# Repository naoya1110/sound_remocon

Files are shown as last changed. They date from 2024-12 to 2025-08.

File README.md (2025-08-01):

# sound_remocon

このリポジトリは、サウンドリモコンの開発データ（KiCadファイル等）をまとめたものです。

## ディレクトリ構成

- **v2/**  
  バージョン2
  - **kicad/**  
    v2用のKiCadプロジェクトファイル
    - `sound_remocon_v2/`：v2用KiCadプロジェクト・Gerberファイル
    - `plot_v2_20250704/`：v2 PCB製造用Gerberファイル
  - **ltspice/**  
    LTspiceシミュレーションファイル
    - `mixer_circuit_simulation.asc`：ミキサー回路シミュレーション
  - **pico_codes/**  
    - `pico_codes\sound_remocon_v2\sound_remocon_v2.ino` ラズパイPico用ファームウェア・コード

- **v1/**  
  バージョン1
  - **kicad/**  
    KiCadプロジェクトファイル、ネットリスト、シンボルライブラリ、フットプリント、Gerberファイルなど。

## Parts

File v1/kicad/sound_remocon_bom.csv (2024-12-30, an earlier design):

Reference | Value | Datasheet | Footprint | Qty | DNP
C1,C2,C3,C4,C5,C6 | 0.1u | ~ | Capacitor_THT:C_Disc_D3.8mm_W2.6mm_P2.50mm | 6
Clpf1 | 1n | ~ | Capacitor_THT:C_Disc_D3.8mm_W2.6mm_P2.50mm | 1
Cls1,Clx1,Cly1,Crs1,Crx1,Cry1 | C | ~ | Capacitor_THT:C_Disc_D3.8mm_W2.6mm_P2.50mm | 6
Cout1 | 4.7u | ~ | Capacitor_THT:C_Disc_D4.7mm_W2.5mm_P5.00mm | 1
J1,J2 | Conn_01x02_Pin | ~ | TerminalBlock:TerminalBlock_bornier-2_P5.08mm | 2
JoyStick_left1,JoyStick_right1 | RKJXV122400R |  | myjoystick:RKJXV122400R | 2
LED1 | LED | ~ | LED_THT:LED_D3.0mm | 1
R1,R2,R3,R4,R5,R6,Rls1,Rls2,Rls3,Rlx1,Rlx2,Rlx3,Rly1,Rly2,Rly3,Rmx1,Rmx2,Rmx3,Rna1,Rna2,Rrs1,Rrs2,Rrs3,Rrx1,Rrx2,Rrx3,Rry1,Rry2,Rry3 | 10k | ~ | Resistor_THT:R_Axial_DIN0207_L6.3mm_D2.5mm_P7.62mm_Horizontal | 29
Rled1 | R | ~ | Resistor_THT:R_Axial_DIN0207_L6.3mm_D2.5mm_P7.62mm_Horizontal | 1
Rlpf1 | 3.3k | ~ | Resistor_THT:R_Axial_DIN0207_L6.3mm_D2.5mm_P7.62mm_Horizontal | 1
Rls4,Rlx4,Rly4,Rrs4,Rrx4,Rry4 | ~ | ~ | Resistor_THT:R_Axial_DIN0207_L6.3mm_D2.5mm_P7.62mm_Horizontal | 6
Rout1,Rout2 | 50k | ~ | Resistor_THT:R_Axial_DIN0207_L6.3mm_D2.5mm_P7.62mm_Horizontal | 2
U1,U2,U3,U4 | NJM4580 | http://www.njr.com/semicon/PDF/NJM4580_E.pdf | Package_DIP:DIP-8_W7.62mm | 4

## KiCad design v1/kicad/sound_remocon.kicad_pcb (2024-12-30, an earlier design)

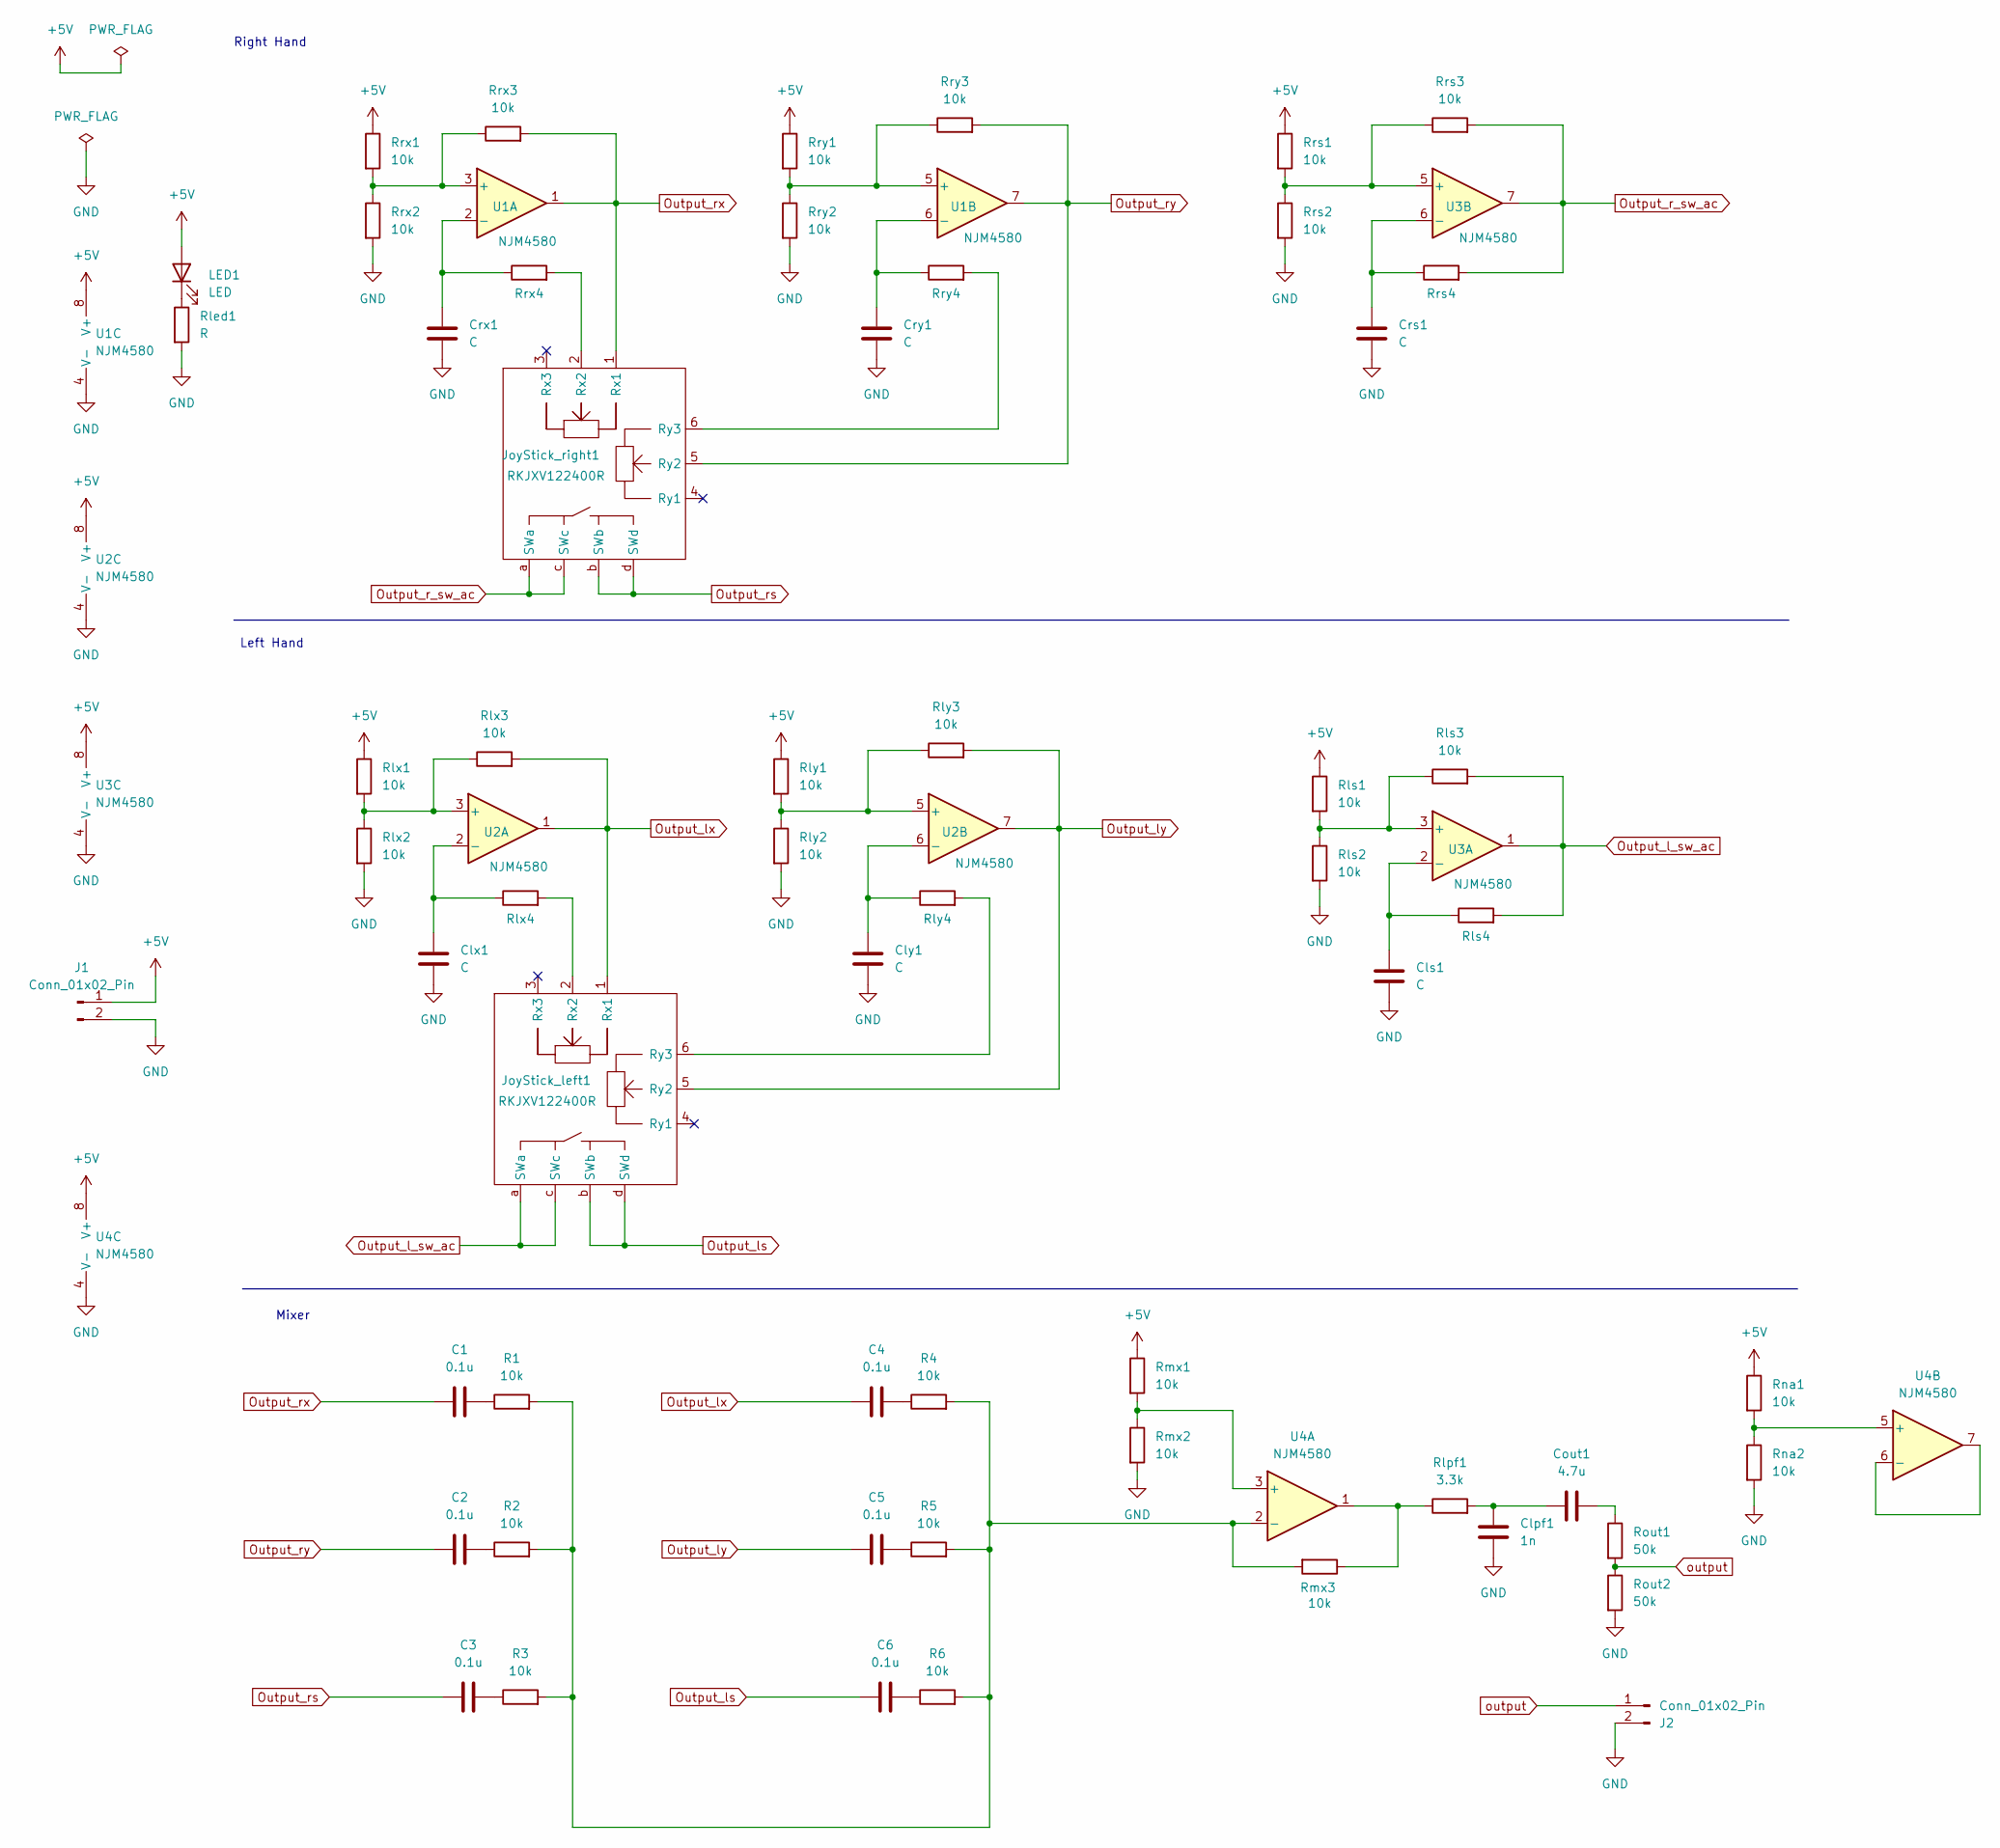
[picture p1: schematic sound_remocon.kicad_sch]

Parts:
C1, C2, C3, C4, C5, C6: 0.1u; C_Disc_D3.8mm_W2.6mm_P2.50mm
Clpf1: 1n; C_Disc_D3.8mm_W2.6mm_P2.50mm
Cls1: C; C_Disc_D3.8mm_W2.6mm_P2.50mm
Clx1: C; C_Disc_D3.8mm_W2.6mm_P2.50mm
Cly1: C; C_Disc_D3.8mm_W2.6mm_P2.50mm
Cout1: 4.7u; C_Disc_D4.7mm_W2.5mm_P5.00mm
Crs1: C; C_Disc_D3.8mm_W2.6mm_P2.50mm
Crx1: C; C_Disc_D3.8mm_W2.6mm_P2.50mm
Cry1: C; C_Disc_D3.8mm_W2.6mm_P2.50mm
J1, J2: Conn_01x02_Pin; TerminalBlock_bornier-2_P5.08mm
JoyStick_left1: RKJXV122400R
JoyStick_right1: RKJXV122400R
LED1: LED; LED_D3.0mm
R1, R2, R3, R4, R5, R6: 10k; R_Axial_DIN0207_L6.3mm_D2.5mm_P7.62mm_Horizontal
Rled1: R; R_Axial_DIN0207_L6.3mm_D2.5mm_P7.62mm_Horizontal
Rlpf1: 3.3k; R_Axial_DIN0207_L6.3mm_D2.5mm_P7.62mm_Horizontal
Rls1, Rls2, Rls3: 10k; R_Axial_DIN0207_L6.3mm_D2.5mm_P7.62mm_Horizontal
Rls4: R_Axial_DIN0207_L6.3mm_D2.5mm_P7.62mm_Horizontal
Rlx1, Rlx2, Rlx3: 10k; R_Axial_DIN0207_L6.3mm_D2.5mm_P7.62mm_Horizontal
Rlx4: R_Axial_DIN0207_L6.3mm_D2.5mm_P7.62mm_Horizontal
Rly1, Rly2, Rly3: 10k; R_Axial_DIN0207_L6.3mm_D2.5mm_P7.62mm_Horizontal
Rly4: R_Axial_DIN0207_L6.3mm_D2.5mm_P7.62mm_Horizontal
Rmx1, Rmx2, Rmx3: 10k; R_Axial_DIN0207_L6.3mm_D2.5mm_P7.62mm_Horizontal
Rna1, Rna2: 10k; R_Axial_DIN0207_L6.3mm_D2.5mm_P7.62mm_Horizontal
Rout1, Rout2: 50k; R_Axial_DIN0207_L6.3mm_D2.5mm_P7.62mm_Horizontal
Rrs1, Rrs2, Rrs3: 10k; R_Axial_DIN0207_L6.3mm_D2.5mm_P7.62mm_Horizontal
Rrs4: R_Axial_DIN0207_L6.3mm_D2.5mm_P7.62mm_Horizontal
Rrx1, Rrx2, Rrx3: 10k; R_Axial_DIN0207_L6.3mm_D2.5mm_P7.62mm_Horizontal
Rrx4: R_Axial_DIN0207_L6.3mm_D2.5mm_P7.62mm_Horizontal
Rry1, Rry2, Rry3: 10k; R_Axial_DIN0207_L6.3mm_D2.5mm_P7.62mm_Horizontal
Rry4: R_Axial_DIN0207_L6.3mm_D2.5mm_P7.62mm_Horizontal
U1, U2, U3, U4: NJM4580; DIP-8_W7.62mm

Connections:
+5V: J1.1, LED1.2 (A), Rls1.1, Rlx1.1, Rly1.1, Rmx1.1, Rna1.1, Rrs1.1, Rrx1.1, Rry1.1, U1.8 (V+), U2.8 (V+), U3.8 (V+), U4.8 (V+)
GND: Clpf1.2, Cls1.2, Clx1.2, Cly1.2, Crs1.2, Crx1.2, Cry1.2, J1.2, J2.2, Rled1.2, Rls2.2, Rlx2.2, Rly2.2, Rmx2.2, Rna2.2, Rout2.2, Rrs2.2, Rrx2.2, Rry2.2, U1.4 (V-), U2.4 (V-), U3.4 (V-), U4.4 (V-)
unnamed: C1.2, R1.1
unnamed: C2.2, R2.1
unnamed: C3.2, R3.1
unnamed: C4.2, R4.1
unnamed: C5.2, R5.1
unnamed: C6.2, R6.1
unnamed: Clpf1.1, Cout1.1, Rlpf1.2
unnamed: Cout1.2, Rout1.1
unnamed 10: JoyStick_left1.2 (Rx2), Rlx4.2; also elsewhere on the board
unnamed 11: JoyStick_left1.6 (Ry3), Rly4.2; also elsewhere on the board
unnamed 12: JoyStick_right1.2 (Rx2), Rrx4.2; also elsewhere on the board
unnamed 13: JoyStick_right1.6 (Ry3), Rry4.2; also elsewhere on the board
unnamed: LED1.1 (K), Rled1.1
unnamed: Rlpf1.1, Rmx3.1, U4.1
unnamed: Rrx1.2, Rrx2.1, Rrx3.1, U1.3 (+)
unnamed: Crx1.1, Rrx4.1, U1.2 (-)
unnamed: Rry1.2, Rry2.1, Rry3.1, U1.5 (+)
unnamed: Cry1.1, Rry4.1, U1.6 (-)
unnamed: Rlx1.2, Rlx2.1, Rlx3.1, U2.3 (+)
unnamed: Clx1.1, Rlx4.1, U2.2 (-)
unnamed: Rly1.2, Rly2.1, Rly3.1, U2.5 (+)
unnamed: Cly1.1, Rly4.1, U2.6 (-)
unnamed: Rls1.2, Rls2.1, Rls3.1, U3.3 (+)
unnamed: Cls1.1, Rls4.1, U3.2 (-)
unnamed: Rrs1.2, Rrs2.1, Rrs3.1, U3.5 (+)
unnamed: Crs1.1, Rrs4.1, U3.6 (-)
unnamed: Rmx1.2, Rmx2.1, U4.3 (+)
unnamed: R1.2, R2.2, R3.2, R4.2, R5.2, R6.2, Rmx3.2, U4.2 (-)
unnamed: Rna1.2, Rna2.1, U4.5 (+)
unnamed: U4.6 (-), U4.7
Output_l_sw_ac: JoyStick_left1.a (SWa), JoyStick_left1.c (SWc), Rls3.2, Rls4.2, U3.1; also elsewhere on the board
Output_ls: C6.1, JoyStick_left1.b (SWb), JoyStick_left1.d (SWd); also elsewhere on the board
Output_lx: C4.1, JoyStick_left1.1 (Rx1), Rlx3.2, U2.1; also elsewhere on the board
Output_ly: C5.1, JoyStick_left1.5 (Ry2), Rly3.2, U2.7; also elsewhere on the board
Output_r_sw_ac: JoyStick_right1.a (SWa), JoyStick_right1.c (SWc), Rrs3.2, Rrs4.2, U3.7; also elsewhere on the board
Output_rs: C3.1, JoyStick_right1.b (SWb), JoyStick_right1.d (SWd); also elsewhere on the board
Output_rx: C1.1, JoyStick_right1.1 (Rx1), Rrx3.2, U1.1; also elsewhere on the board
Output_ry: C2.1, JoyStick_right1.5 (Ry2), Rry3.2, U1.7; also elsewhere on the board
output: J2.1, Rout1.2, Rout2.1

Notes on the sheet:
Mixer
Left Hand
Right Hand

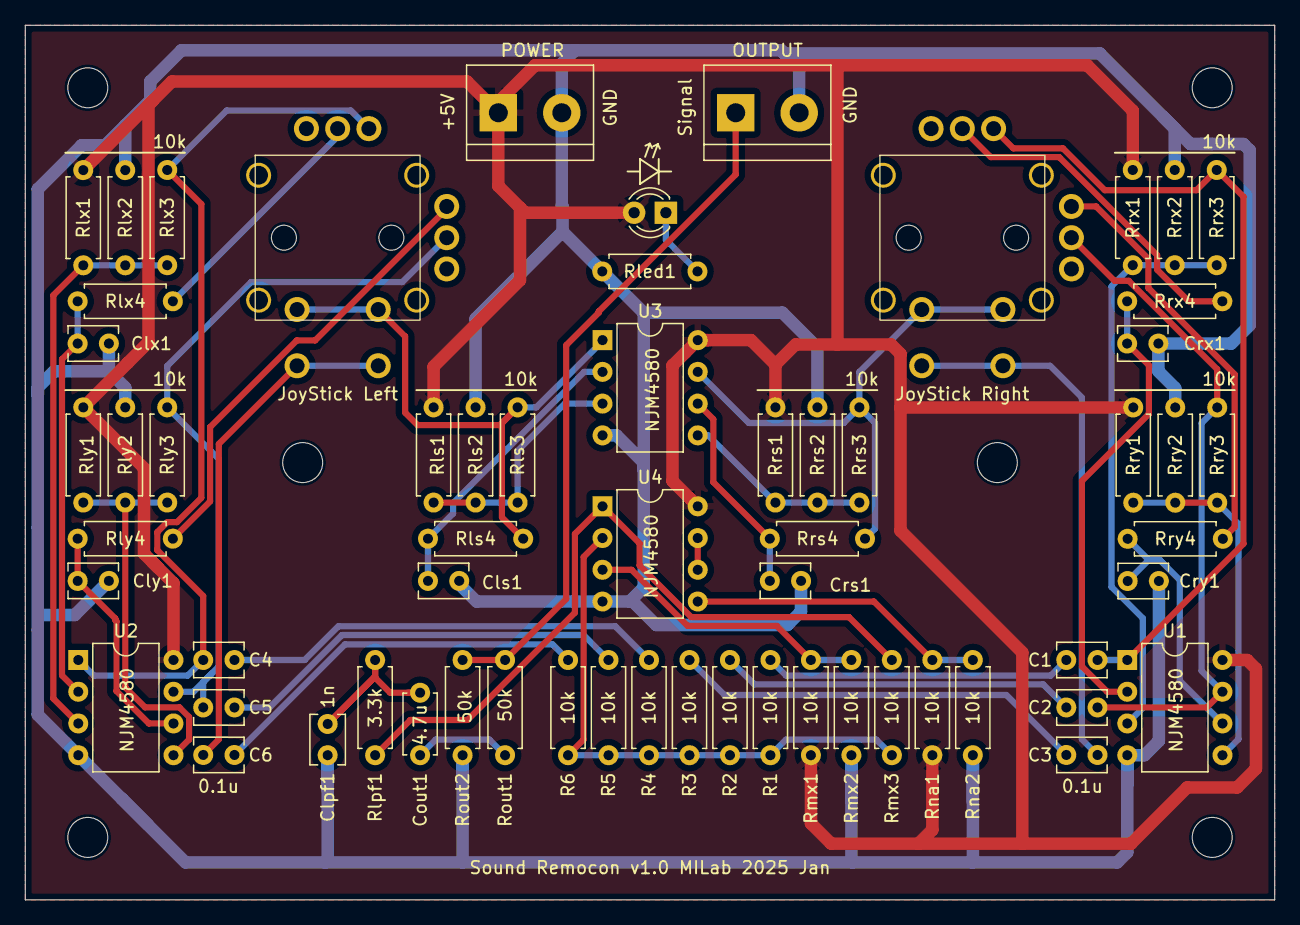
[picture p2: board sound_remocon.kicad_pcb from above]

Board: 2 copper layers, 100.0 x 70.0 mm, 62 parts (0 on the bottom side), 41 nets.

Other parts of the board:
JoyStick Left: RKJXV122400R
JoyStick Right: RKJXV122400R

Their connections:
unnamed 10: JoyStick Left.2 (Rx2); also elsewhere on the board
unnamed 11: JoyStick Left.6 (Ry3); also elsewhere on the board
unnamed 12: JoyStick Right.2 (Rx2); also elsewhere on the board
unnamed 13: JoyStick Right.6 (Ry3); also elsewhere on the board
Output_l_sw_ac: JoyStick Left.a (SWa), JoyStick Left.c (SWc); also elsewhere on the board
Output_ls: JoyStick Left.b (SWb), JoyStick Left.d (SWd); also elsewhere on the board
Output_lx: JoyStick Left.1 (Rx1); also elsewhere on the board
Output_ly: JoyStick Left.5 (Ry2); also elsewhere on the board
Output_r_sw_ac: JoyStick Right.a (SWa), JoyStick Right.c (SWc); also elsewhere on the board
Output_rs: JoyStick Right.b (SWb), JoyStick Right.d (SWd); also elsewhere on the board
Output_rx: JoyStick Right.1 (Rx1); also elsewhere on the board
Output_ry: JoyStick Right.5 (Ry2); also elsewhere on the board

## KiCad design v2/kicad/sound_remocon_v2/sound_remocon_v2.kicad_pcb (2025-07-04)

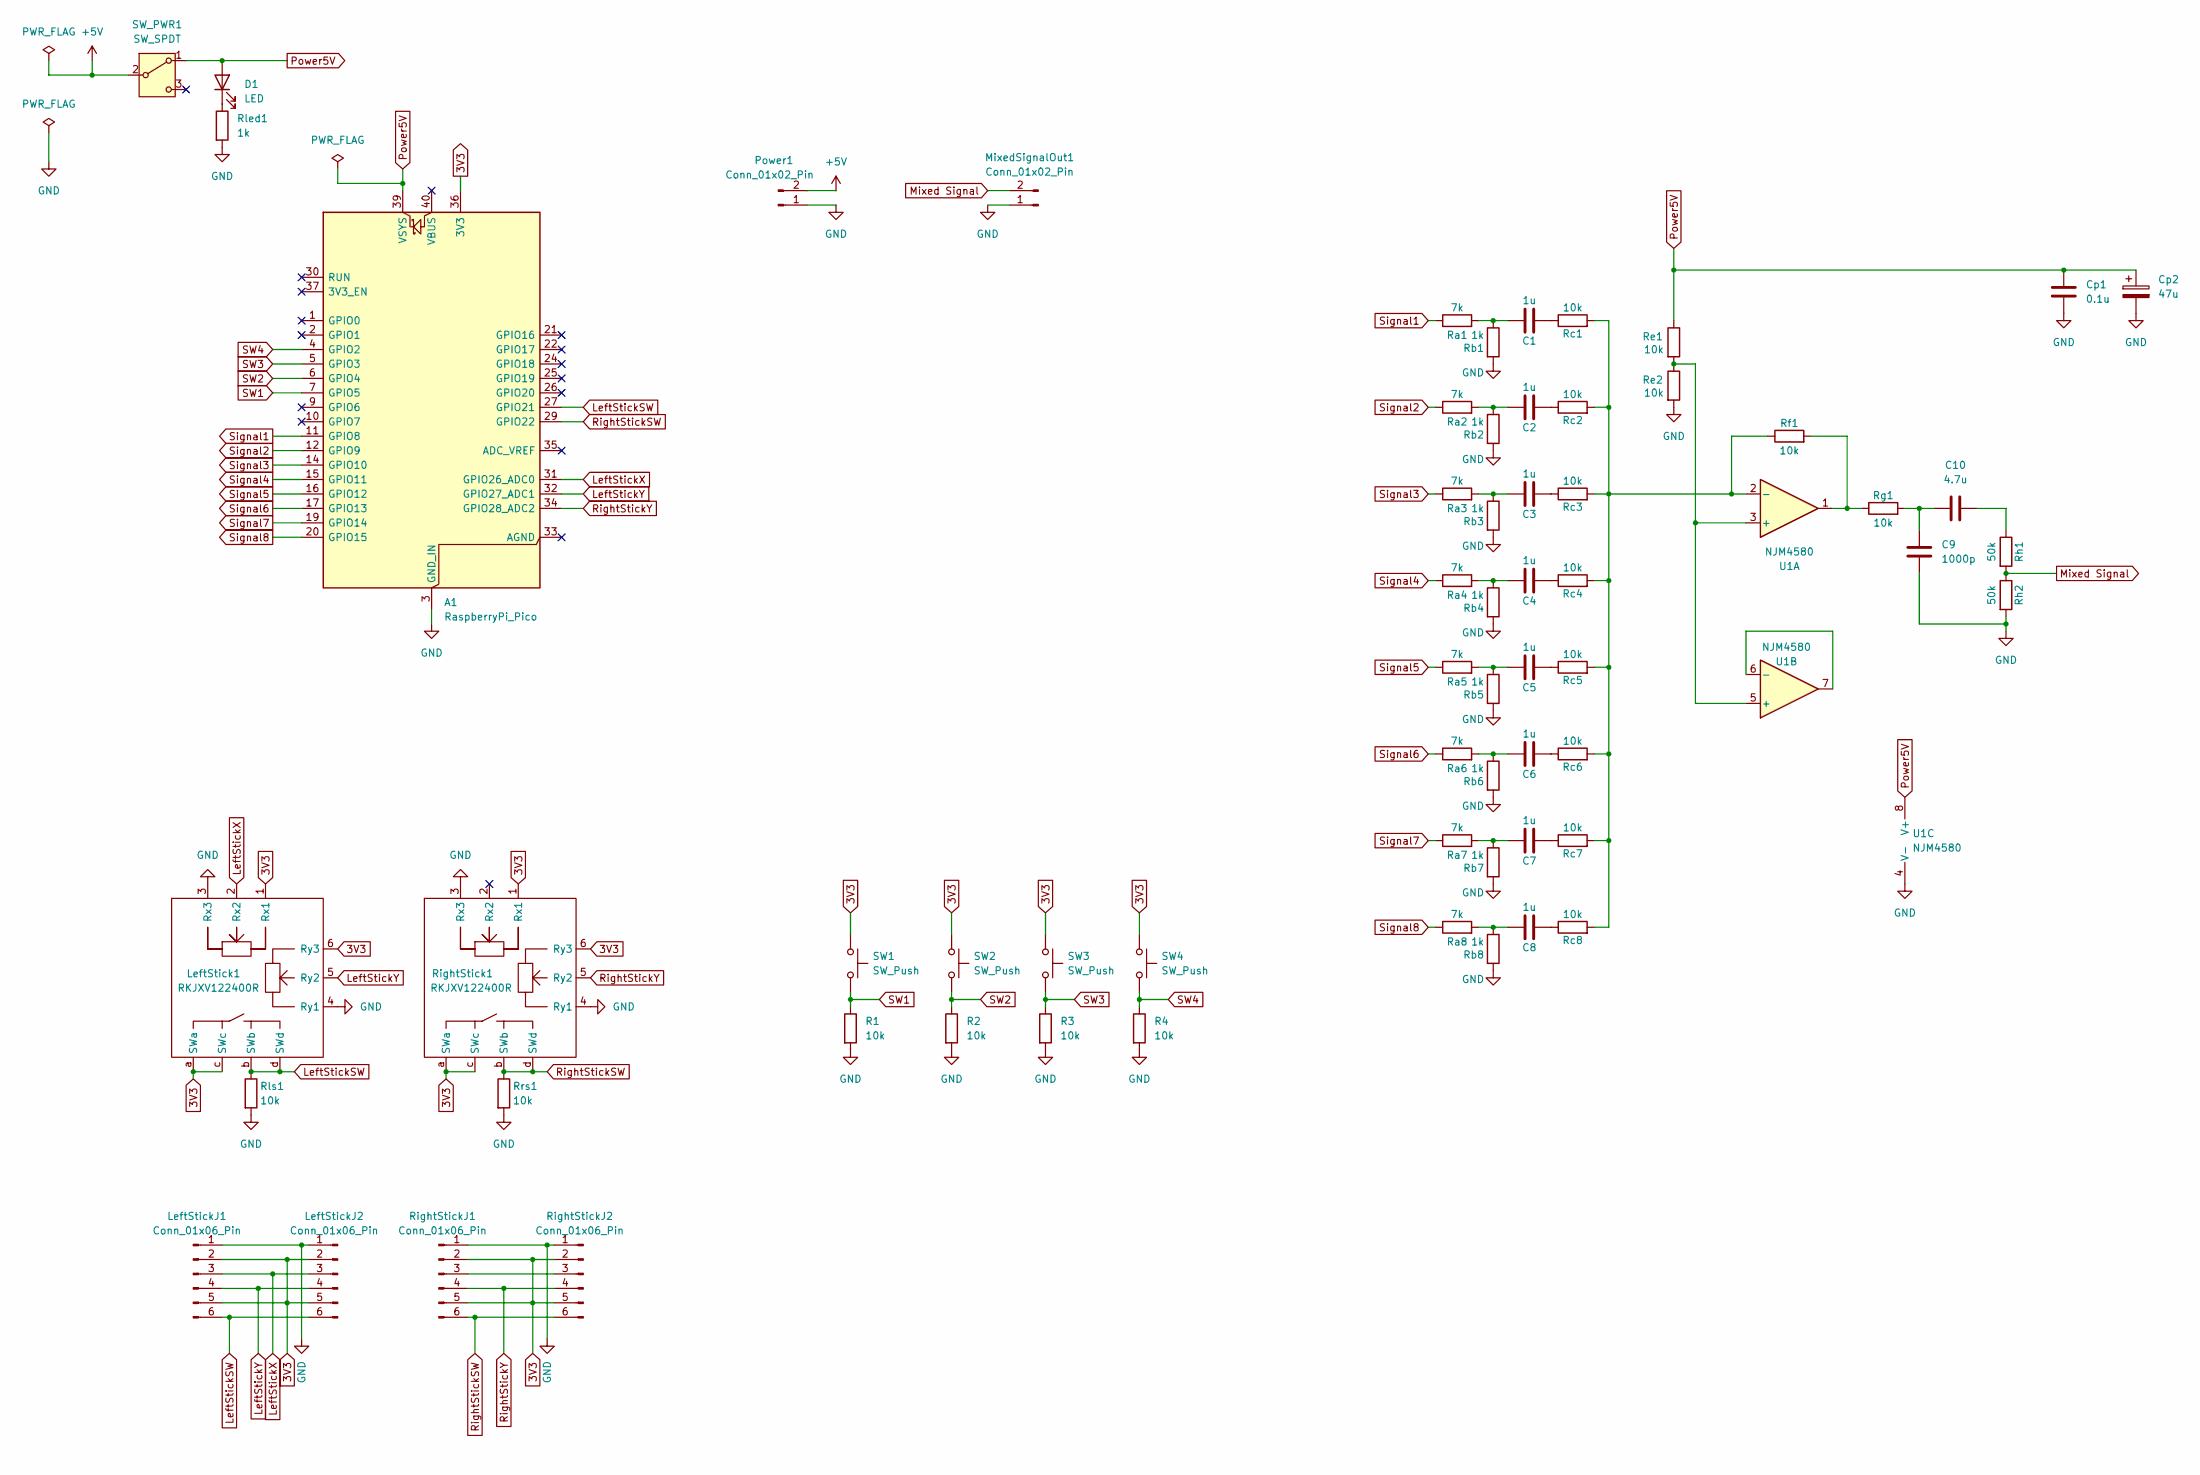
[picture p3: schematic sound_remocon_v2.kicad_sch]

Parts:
A1: RaspberryPi_Pico; RaspberryPi_Pico_Common_Unspecified
C1, C2, C3, C4, C5, C6, C7, C8: 1u; C_Disc_D5.1mm_W3.2mm_P5.00mm
C9: 1000p; C_Disc_D5.1mm_W3.2mm_P5.00mm
C10: 4.7u; C_Disc_D5.1mm_W3.2mm_P5.00mm
Cp1: 0.1u; C_Disc_D5.1mm_W3.2mm_P5.00mm
Cp2: 47u; CP_Radial_D8.0mm_P5.00mm
D1: LED; LED_D3.0mm
LeftStick1: RKJXV122400R
LeftStickJ1, LeftStickJ2: Conn_01x06_Pin; PinHeader_1x06_P2.54mm_Vertical
MixedSignalOut1: Conn_01x02_Pin; TerminalBlock_bornier-2_P5.08mm
Power1: Conn_01x02_Pin; TerminalBlock_bornier-2_P5.08mm
R1, R2, R3, R4: 10k; R_Axial_DIN0207_L6.3mm_D2.5mm_P2.54mm_Vertical
Ra1, Ra2, Ra3, Ra4, Ra5, Ra6, Ra7, Ra8: 7k; R_Axial_DIN0207_L6.3mm_D2.5mm_P2.54mm_Vertical
Rb1, Rb2, Rb3, Rb4, Rb5, Rb6, Rb7, Rb8: 1k; R_Axial_DIN0207_L6.3mm_D2.5mm_P2.54mm_Vertical
Rc1, Rc2, Rc3, Rc4, Rc5, Rc6, Rc7, Rc8: 10k; R_Axial_DIN0207_L6.3mm_D2.5mm_P2.54mm_Vertical
Re1, Re2: 10k; R_Axial_DIN0207_L6.3mm_D2.5mm_P2.54mm_Vertical
Rf1: 10k; R_Axial_DIN0207_L6.3mm_D2.5mm_P2.54mm_Vertical
Rg1: 10k; R_Axial_DIN0207_L6.3mm_D2.5mm_P2.54mm_Vertical
Rh1, Rh2: 50k; R_Axial_DIN0207_L6.3mm_D2.5mm_P2.54mm_Vertical
RightStick1: RKJXV122400R
RightStickJ1, RightStickJ2: Conn_01x06_Pin; PinHeader_1x06_P2.54mm_Vertical
Rled1: 1k; R_Axial_DIN0207_L6.3mm_D2.5mm_P2.54mm_Vertical
Rls1: 10k; R_Axial_DIN0207_L6.3mm_D2.5mm_P2.54mm_Vertical
Rrs1: 10k; R_Axial_DIN0207_L6.3mm_D2.5mm_P2.54mm_Vertical
SW1, SW2, SW3, SW4: SW_Push; SW_PUSH_6mm_H7.3mm
SW_PWR1: SW_SPDT; PinHeader_1x03_P2.54mm_Vertical
U1: NJM4580; DIP-8_W7.62mm_Socket

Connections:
3V3: A1.36 (3V3), LeftStick1.1 (Rx1), LeftStick1.6 (Ry3), LeftStick1.a (SWa), LeftStick1.c (SWc), LeftStickJ1.2, LeftStickJ1.5, LeftStickJ2.2, LeftStickJ2.5, RightStick1.1 (Rx1), RightStick1.6 (Ry3), RightStick1.a (SWa), RightStick1.c (SWc), RightStickJ1.2, RightStickJ1.5, RightStickJ2.2, RightStickJ2.5, SW1.1, SW2.1, SW3.1, SW4.1
+5V: Power1.2, SW_PWR1.2 (B)
GND: A1.3 (GND_IN), A1.8 (GND), A1.13 (GND), A1.18 (GND), A1.23 (GND), A1.28 (GND), A1.38 (GND), C9.2, Cp1.2, Cp2.2, LeftStick1.3 (Rx3), LeftStick1.4 (Ry1), LeftStickJ1.1, LeftStickJ2.1, MixedSignalOut1.1, Power1.1, R1.2, R2.2, R3.2, R4.2, Rb1.2, Rb2.2, Rb3.2, Rb4.2, Rb5.2, Rb6.2, Rb7.2, Rb8.2, Re2.2, Rh2.2, RightStick1.3 (Rx3), RightStick1.4 (Ry1), RightStickJ1.1, RightStickJ2.1, Rled1.2, Rls1.2, Rrs1.2, U1.4 (V-)
LeftStickSW: A1.27 (GPIO21), LeftStick1.b (SWb), LeftStick1.d (SWd), LeftStickJ1.6, LeftStickJ2.6, Rls1.1
LeftStickX: A1.31 (GPIO26_ADC0), LeftStick1.2 (Rx2), LeftStickJ1.3, LeftStickJ2.3
LeftStickY: A1.32 (GPIO27_ADC1), LeftStick1.5 (Ry2), LeftStickJ1.4, LeftStickJ2.4
Mixed Signal: MixedSignalOut1.2, Rh1.2, Rh2.1
unnamed: C1.1, Ra1.2, Rb1.1
unnamed: C1.2, Rc1.1
unnamed: C2.1, Ra2.2, Rb2.1
unnamed: C2.2, Rc2.1
unnamed: C3.1, Ra3.2, Rb3.1
unnamed: C3.2, Rc3.1
unnamed: C4.1, Ra4.2, Rb4.1
unnamed: C4.2, Rc4.1
unnamed: C5.1, Ra5.2, Rb5.1
unnamed: C5.2, Rc5.1
unnamed: C6.1, Ra6.2, Rb6.1
unnamed: C6.2, Rc6.1
unnamed: C7.1, Ra7.2, Rb7.1
unnamed: C7.2, Rc7.1
unnamed: C8.1, Ra8.2, Rb8.1
unnamed: C8.2, Rc8.1
unnamed: C9.1, C10.1, Rg1.2
unnamed: C10.2, Rh1.1
unnamed: D1.1 (K), Rled1.1
unnamed: Rf1.2, Rg1.1, U1.1
unnamed: RightStickJ1.3, RightStickJ2.3
unnamed: Re1.2, Re2.1, U1.3 (+), U1.5 (+)
unnamed: Rc1.2, Rc2.2, Rc3.2, Rc4.2, Rc5.2, Rc6.2, Rc7.2, Rc8.2, Rf1.1, U1.2 (-)
unnamed: U1.6 (-), U1.7
Power5V: A1.39 (VSYS), Cp1.1, Cp2.1, D1.2 (A), Re1.1, SW_PWR1.1 (A), U1.8 (V+)
RightStickSW: A1.29 (GPIO22), RightStick1.b (SWb), RightStick1.d (SWd), RightStickJ1.6, RightStickJ2.6, Rrs1.1
RightStickY: A1.34 (GPIO28_ADC2), RightStick1.5 (Ry2), RightStickJ1.4, RightStickJ2.4
SW1: A1.7 (GPIO5), R1.1, SW1.2
SW2: A1.6 (GPIO4), R2.1, SW2.2
SW3: A1.5 (GPIO3), R3.1, SW3.2
SW4: A1.4 (GPIO2), R4.1, SW4.2
Signal1: A1.11 (GPIO8), Ra1.1
Signal2: A1.12 (GPIO9), Ra2.1
Signal3: A1.14 (GPIO10), Ra3.1
Signal4: A1.15 (GPIO11), Ra4.1
Signal5: A1.16 (GPIO12), Ra5.1
Signal6: A1.17 (GPIO13), Ra6.1
Signal7: A1.19 (GPIO14), Ra7.1
Signal8: A1.20 (GPIO15), Ra8.1

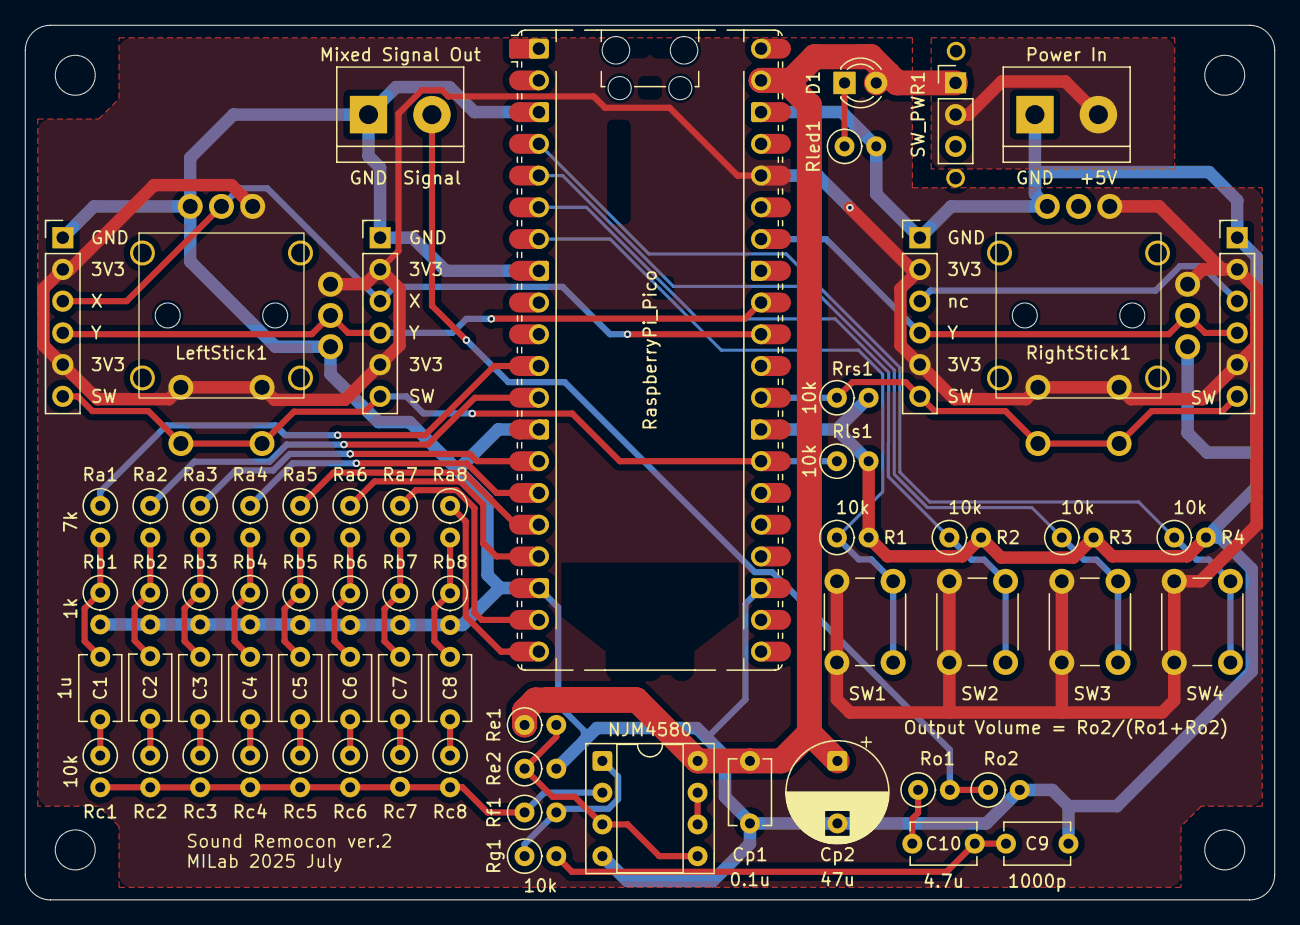
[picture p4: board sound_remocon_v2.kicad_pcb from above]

Board: 2 copper layers, 100.0 x 70.0 mm, 65 parts (0 on the bottom side), 46 nets.

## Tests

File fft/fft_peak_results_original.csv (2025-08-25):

set_freq | peak_freq | peak_amp
100 | 102.28271484375 | 110822644.69393839
100 | 102.28271484375 | 109610194.00332768
100 | 102.28271484375 | 110941097.44255918
200 | 199.18212890625 | 146942708.80933228
200 | 199.18212890625 | 146905766.7205551
200 | 199.18212890625 | 146938645.7056857
300 | 301.46484375 | 134942480.57791048
300 | 301.46484375 | 134892414.5634557
300 | 301.46484375 | 134891858.514829
400 | 398.3642578125 | 130546858.87400515
400 | 398.3642578125 | 130193331.60876445
400 | 398.3642578125 | 130173670.83407335
500 | 500.64697265625 | 149023842.75767374
500 | 500.64697265625 | 149005767.7896897
500 | 500.64697265625 | 149063382.59341773
700 | 699.8291015625 | 152360747.80973482
700 | 699.8291015625 | 152310809.8194087
700 | 699.8291015625 | 152324601.91871202
1000 | 1001.2939453125 | 138701946.01151094
1000 | 1001.2939453125 | 138632567.4426484
1000 | 1001.2939453125 | 138474415.8553558
1500 | 1501.94091796875 | 121949110.36624959
1500 | 1501.94091796875 | 122055128.9324365
1500 | 1501.94091796875 | 122013601.38068081
2000 | 2002.587890625 | 101153725.60568443
2000 | 2002.587890625 | 101194015.95892039
2000 | 2002.587890625 | 101314373.07038775
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

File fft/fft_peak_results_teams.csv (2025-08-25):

set_freq | peak_freq | peak_amp
100 | 102.28271484375 | 31231.736016721836
100 | 102.28271484375 | 33006.16926533201
100 | 102.28271484375 | 32784.54038184306
200 | 199.18212890625 | 47750.30960214396
200 | 199.18212890625 | 48332.66783760091
200 | 199.18212890625 | 50651.24897691117
300 | 301.46484375 | 41458.6416791831
300 | 301.46484375 | 42439.48505661602
300 | 301.46484375 | 43880.11808617846
400 | 398.3642578125 | 42504.89072119838
400 | 398.3642578125 | 43943.29749630875
400 | 398.3642578125 | 45576.19671474346
500 | 500.64697265625 | 52467.1310748347
500 | 500.64697265625 | 50554.434500131356
500 | 500.64697265625 | 52746.23256196418
700 | 699.8291015625 | 46518.489389921175
700 | 699.8291015625 | 47544.78941631199
700 | 699.8291015625 | 46485.07630346496
1000 | 1001.2939453125 | 46889.30547494397
1000 | 1001.2939453125 | 46721.88307430264
1000 | 1001.2939453125 | 45905.37994625167
1500 | 1501.94091796875 | 37528.30530992934
1500 | 1501.94091796875 | 37454.981361012484
1500 | 1501.94091796875 | 37312.751572634246
2000 | 2002.587890625 | 30711.57403262908
2000 | 2002.587890625 | 31003.40602399148
2000 | 2002.587890625 | 30817.41969284885
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

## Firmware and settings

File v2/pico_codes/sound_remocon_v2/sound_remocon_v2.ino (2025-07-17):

// Raspberry Pi Pico 2 Pin Configuration
//
// INPUT                          |   OUTPUT
// -------------------------------|--------------------------------------
// SW1 ----------------> GPIO5 ---|-- GPIO8 ------> Signal1 ----- 800Hz
// SW2 ----------------> GPIO4 ---|-- GPIO9 ------> Signal2 ----- 850Hz
// SW3 ----------------> GPIO3 ---|-- GPIO10 -----> Signal3 ----- 900Hz
// SW4 ----------------> GPIO2 ---|-- GPIO11 -----> Signal4 ----- 950Hz
// LEFT STICK SW ------> GPIO21 --|-- GPIO12 -----> Signal5 ----- 1000Hz
// RIGHT STICK SW -----> GPIO22 --|-- GPIO13 -----> Signal6 ----- 1050Hz
// LEFT STICK X -------> ADC0 ----|-- None -------> None
// LEFT STICK Y -------> ADC1 ----|-- GPIO14 -----> Signal7 ----- 510-550-590Hz
// RIGHT STICK Y ------> ADC2 ----|-- GPIO15 -----> Signal8 ----- 660-700-740Hz
// -------------------------------|--------------------------------------



#include <Arduino.h>

#define TONE_USE_INT
#define TONE_PITCH 440
#include <TonePitch.h>

// ボタンスイッチ
#define PIN_SW1 5
#define PIN_SW2 4
#define PIN_SW3 3
#define PIN_SW4 2

// スティックのボタンスイッチ
#define PIN_L_ST_SW 21
#define PIN_R_ST_SW 22

// スティックのXY
#define PIN_L_ST_X A0
#define PIN_L_ST_Y A1
#define PIN_R_ST_Y A2

// 矩形波信号出力
#define PIN_SIGNAL1 8
#define PIN_SIGNAL2 9
#define PIN_SIGNAL3 10
#define PIN_SIGNAL4 11
#define PIN_SIGNAL5 12
#define PIN_SIGNAL6 13
#define PIN_SIGNAL7 14
#define PIN_SIGNAL8 15

// 信号の基本周波数
#define FREQ_SIGNAL1 800
#define FREQ_SIGNAL2 850
#define FREQ_SIGNAL3 900
#define FREQ_SIGNAL4 950
#define FREQ_SIGNAL5 1000
#define FREQ_SIGNAL6 1050
#define FREQ_SIGNAL7 550
#define FREQ_SIGNAL8 700

#define FREQ_STEP 10

int oldSw1State = 0;
int oldSw2State = 0;
int oldSw3State = 0;
int oldSw4State = 0;
int oldLeftStickSwState = 0;
int oldRightStickSwState = 0;
int oldMappedLeftStickXValue = 0;
int oldMappedLeftStickYValue = 0;
int oldMappedRightStickYValue = 0;

// スティックの値
int leftStickXValue = 0;
int leftStickYValue = 0;
int rightStickYValue = 0;


void setup() {
  Serial.begin(9600);
  
  // 入力ピン
  pinMode(PIN_SW1, INPUT);      // digital
  pinMode(PIN_SW2, INPUT);      // digital
  pinMode(PIN_SW3, INPUT);      // digital
  pinMode(PIN_SW4, INPUT);      // digital
  pinMode(PIN_L_ST_SW, INPUT);  // digital
  pinMode(PIN_R_ST_SW, INPUT);  // digital
  pinMode(PIN_L_ST_X, INPUT);   // analog
  pinMode(PIN_L_ST_Y, INPUT);   // analog
  pinMode(PIN_R_ST_Y, INPUT);   // analog

  // 出力ピン
  pinMode(LED_BUILTIN, OUTPUT); // ボード上のLED

  pinMode(PIN_SIGNAL1, OUTPUT);  // SW1
  pinMode(PIN_SIGNAL2, OUTPUT);  // SW2
  pinMode(PIN_SIGNAL3, OUTPUT);  // SW3
  pinMode(PIN_SIGNAL4, OUTPUT);  // SW4
  pinMode(PIN_SIGNAL5, OUTPUT);  // Left Stick SW
  pinMode(PIN_SIGNAL6, OUTPUT);  // Right Stick SW
  pinMode(PIN_SIGNAL7, OUTPUT);  // Left Stick X
  pinMode(PIN_SIGNAL8, OUTPUT);  // Left Stick Y

  tone(PIN_SIGNAL7, FREQ_SIGNAL7);
  tone(PIN_SIGNAL8, FREQ_SIGNAL8);
}

// スティックの味付け関数
int map_stick(int x) {
  int y;
  if (abs(x) < 75) {
    y = 0;
  } else {
    y = round(x/90);
    y = min(4, y);
    y = max(-4, y);
  }
  return y;
}

void loop() {

  Serial.println("Calibating.....");
  // スティックのキャリブレーション

  // スティックのニュートラル値
  int neutralLeftStickX = 0;
  int neutralLeftStickY = 0;
  int neutralRightStickY = 0;
  int nCalib = 30;

  for (int i=0; i<nCalib; i++) {
    digitalWrite(LED_BUILTIN, HIGH);
    neutralLeftStickX += analogRead(PIN_L_ST_X);
    neutralLeftStickY += analogRead(PIN_L_ST_Y);
    neutralRightStickY += analogRead(PIN_R_ST_Y);
    delay(100);
    digitalWrite(LED_BUILTIN, LOW);
    delay(50);
  }

  neutralLeftStickX /= nCalib;
  neutralLeftStickY /= nCalib;
  neutralRightStickY /= nCalib;
  
  Serial.println("Stick Neutral Values");
  Serial.print(neutralLeftStickX);
  Serial.print("\t");
  Serial.print(neutralLeftStickY);
  Serial.print("\t");
  Serial.println(neutralRightStickY);
  delay(2000);

  while(1) {
    digitalWrite(LED_BUILTIN, HIGH);

    // ボタンスイッチの値を読み取り
    int sw1State = digitalRead(PIN_SW1);
    int sw2State = digitalRead(PIN_SW2);
    int sw3State = digitalRead(PIN_SW3);
    int sw4State = digitalRead(PIN_SW4);
    int leftStickSwState = digitalRead(PIN_L_ST_SW);
    int rightStickSwState = digitalRead(PIN_R_ST_SW);

    // スティックの値の読み取り
    leftStickXValue = analogRead(PIN_L_ST_X);
    leftStickYValue = analogRead(PIN_L_ST_Y);
    rightStickYValue = analogRead(PIN_R_ST_Y);

    leftStickXValue -= neutralLeftStickX;
    leftStickYValue -= neutralLeftStickY;
    rightStickYValue -= neutralRightStickY;

    // スティックの値をマップ -4から+4にマップ
    int mappedLeftStickXValue = map_stick(leftStickXValue);
    int mappedLeftStickYValue = map_stick(leftStickYValue);
    int mappedRightStickYValue = map_stick(rightStickYValue);

    // SW1/Signal1の信号制御
    if (sw1State != oldSw1State) {
      if (sw1State == 1) {
        tone(PIN_SIGNAL1, FREQ_SIGNAL1);
      } else if (sw1State == 0) {
        noTone(PIN_SIGNAL1);
      }
    }

    // SW2/Signal2の信号制御
    if (sw2State != oldSw2State) {
      if (sw2State == 1) {
        tone(PIN_SIGNAL2, FREQ_SIGNAL2);
      } else if (sw2State == 0) {
        noTone(PIN_SIGNAL2);
      }
    }

    // SW3/Signal3の信号制御
    if (sw3State != oldSw3State) {
      if (sw3State == 1) {
        tone(PIN_SIGNAL3, FREQ_SIGNAL3);
      } else if (sw3State == 0) {
        noTone(PIN_SIGNAL3);
      }
    }

    // SW4/Signal4の信号制御
    if (sw4State != oldSw4State) {
      if (sw4State == 1) {
        tone(PIN_SIGNAL4, FREQ_SIGNAL4);
      } else if (sw4State == 0) {
        noTone(PIN_SIGNAL4);
      }
    }

    // LeftStickSW/Signal5の信号制御
    if (leftStickSwState != oldLeftStickSwState) {
      if (leftStickSwState == 1) {
        tone(PIN_SIGNAL5, FREQ_SIGNAL5);
      } else if (leftStickSwState == 0) {
        noTone(PIN_SIGNAL5);
      }
    }

    // RightStickSW/Signal6の信号制御
    if (rightStickSwState != oldRightStickSwState) {
      if (rightStickSwState == 1) {
        tone(PIN_SIGNAL6, FREQ_SIGNAL6);
      } else if (rightStickSwState == 0) {
        noTone(PIN_SIGNAL6);
      }
    }

    // // LeftStickXValue/Signal7の信号制御
    // if (mappedLeftStickXValue != oldMappedLeftStickXValue){
    //   int f = FREQ_SIGNAL7 + mappedLeftStickXValue * FREQ_STEP;
    //   tone(PIN_SIGNAL7, f);
    // }

    // LeftStickYValue/Signal7の信号制御
    if (mappedLeftStickYValue != oldMappedLeftStickYValue){
      int f = FREQ_SIGNAL7 + mappedLeftStickYValue * FREQ_STEP;
      tone(PIN_SIGNAL7, f);
    }

    // RightStickYValue/Signal8の信号制御
    if (mappedRightStickYValue != oldMappedRightStickYValue){
      int f = FREQ_SIGNAL8 + mappedRightStickYValue * FREQ_STEP;
      tone(PIN_SIGNAL8, f);
    }



    Serial.print(sw1State);
    Serial.print("\t");
    Serial.print(sw2State);
    Serial.print("\t");
    Serial.print(sw3State);
    Serial.print("\t");
    Serial.print(sw4State);
    Serial.print("\t");
    Serial.print(leftStickSwState);
    Serial.print("\t");
    Serial.print(rightStickSwState);
    Serial.print("\t");
    Serial.print(leftStickXValue);
    Serial.print("\t");
    Serial.print(mappedLeftStickXValue);
    Serial.print("\t");
    Serial.print(leftStickYValue);
    Serial.print("\t");
    Serial.print(mappedLeftStickYValue);
    Serial.print("\t");
    Serial.print(rightStickYValue);
    Serial.print("\t");
    Serial.println(mappedRightStickYValue);

    // 古いデータを保持
    oldSw1State = sw1State;
    oldSw2State = sw2State;
    oldSw3State = sw3State;
    oldSw4State = sw4State;

    oldLeftStickSwState = leftStickSwState;
    oldRightStickSwState = rightStickSwState;

    oldMappedLeftStickXValue = mappedLeftStickXValue;
    oldMappedLeftStickYValue = mappedLeftStickYValue;
    oldMappedRightStickYValue = mappedRightStickYValue;


    delay(10);  // wait for a second

  }

  


}

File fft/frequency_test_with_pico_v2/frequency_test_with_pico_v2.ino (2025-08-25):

#include <Arduino.h>
#define TONE_USE_INT 
#define TONE_PITCH 440 
#include <TonePitch.h>
#define PIN_SIG_OUT 7

void setup() {
  pinMode(PIN_SIG_OUT, OUTPUT);
  Serial.begin(9600); // Start serial communication at 9600 baud
  Serial.println("Ready to receive frequency (Hz). Send a number, e.g., '500'");
  Serial.println("A tone will begin after the first valid input.");
}

void loop() {
  if (Serial.available()) {
    // Read the incoming string until a newline character is received
    String inputString = Serial.readStringUntil('\n');

    // Convert the string to an integer
    int freq = inputString.toInt();

    // Check if the conversion was successful and the number is a valid frequency
    if (freq > 0) {
      Serial.print("Setting tone frequency to: ");
      Serial.print(freq);
      Serial.println(" Hz");
      tone(PIN_SIG_OUT, freq); // Change the tone frequency
    } else {
      Serial.println("Invalid input. Please send a positive integer.");
    }
  }
}
